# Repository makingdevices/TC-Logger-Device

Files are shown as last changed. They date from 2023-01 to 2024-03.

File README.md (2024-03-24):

<!-- Improved compatibility of back to top link: See: https://github.com/othneildrew/Best-README-Template/pull/73 -->

<!--
*** Thanks for checking out the Best-README-Template. If you have a suggestion
*** that would make this better, please fork the repo and create a pull request
*** or simply open an issue with the tag "enhancement".
*** Don't forget to give the project a star!
*** Thanks again! Now go create something AMAZING! :D
-->

<!-- PROJECT SHIELDS -->
<!--
*** I'm using markdown "reference style" links for readability.
*** Reference links are enclosed in brackets [ ] instead of parentheses ( ).
*** See the bottom of this document for the declaration of the reference variables
*** for contributors-url, forks-url, etc. This is an optional, concise syntax you may use.
*** https://www.markdownguide.org/basic-syntax/#reference-style-links
-->
[][ig-url]
[][sponsor-url]
[][stars-url]
[][issues-url]
[][linkedin-url]

<!-- PROJECT LOGO -->
<br />
<div align="center">
  <a href="https://makingdevices.com/links/">
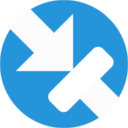
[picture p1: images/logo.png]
    
  </a>

<h3 align="center">Making Devices</h3>

  <p align="center">
    Open Source projects where we struggle with engineering, electronics, coding and who knows what else... In this case, TC Logger Device is a very simple USB thermocouple reader, so hopefully you may find it interesting ;)
  </p>
</div>

<!-- TABLE OF CONTENTS -->
<details>
  <summary>Table of Contents</summary>
  <ol>
    <li>
      <a href="#about-the-project">About The Project</a>
      <ul>
        <li><a href="#built-with">Built With</a></li>
      </ul>
    </li>
    <li>
      <a href="#Build-one">Build one</a>
      <ul>
      </ul>
    </li>
    <li><a href="#usage">Usage</a></li>
    <li><a href="#roadmap">Roadmap</a></li>
    <li><a href="#license">License</a></li>
    <li><a href="#contact">Contact</a></li>
    <li><a href="#Sponsor">Sponsor</a></li>
  </ol>
</details>

<!-- ABOUT THE PROJECT -->
## About The Project

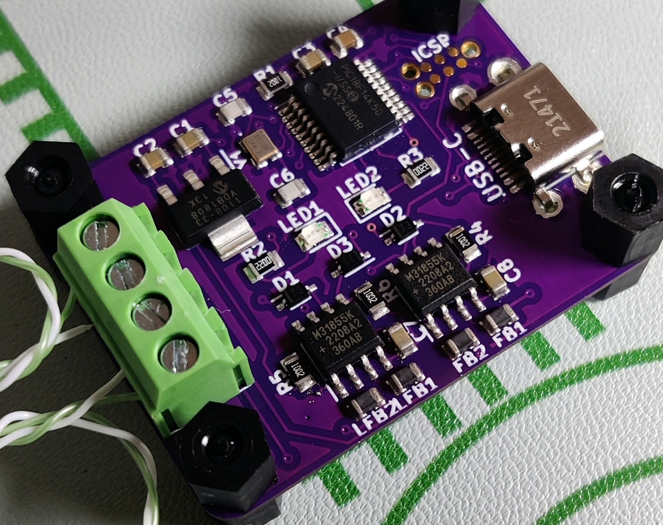
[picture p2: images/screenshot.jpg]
Bytes Counter Shot
[](https://makingdevices.com/TCLogger-Device)

TC Logger Device is a simple thermocouple USB reader: help you to measure any proccess you need using the USB protocol an a simple software developed in Python. The project was chosen to test the USB communication, explore the interface PC-Embedded system. The project is able to use two thermocouple at the same time and share the data to the computer at a speed of 5Hz. (5 samples per second). The main microprocessor is the PIC18F14K50.

<p align="right">(<a href="#readme-top">back to top</a>)</p>

### Built With

[][PIC-url]
[][MPLAB-C-url]
[][kicad-url]
[][sponsor-url]

<p align="right">(<a href="#readme-top">back to top</a>)</p>

<!-- GETTING STARTED -->

## Build one
The project is finished and no further development will be made. The device is safe, stable and It was tested. 

1. Get the gerber files for the latest version: [V1.2b](https://github.com/makingdevices/TC-Logger-Device/blob/main/Gerber/v1.2b/ThermoDeviceLogger-v_1.2b.zip) 
2. Send them to a PCB manufacturer ([Our Sponsor is PCBWAY][sponsor-url])
3. You can read the user manual: [V1.0](https://github.com/makingdevices/TC-Logger-Device/blob/main/Output_PDF/Manual_ThermoLoggerv1_0.pdf) 

<p align="right">(<a href="#readme-top">back to top</a>)</p>

<!-- USAGE EXAMPLES -->
## Usage

Instructions of use:

- The LED will light up if a thermocouple is not detected.
- Use the Python software to communicate with the board.

You can read the user manual: [V1.0](https://github.com/makingdevices/TC-Logger-Device/blob/main/Output_PDF/Manual_ThermoLoggerv1_0.pdf) 

<p align="right">(<a href="#readme-top">back to top</a>)</p>

<!-- ROADMAP -->
## Roadmap

- [x] Finish the firmware for the PIC18F14K50
- [x] Validate firmware
- [x] Finish PC software
    - [x] Implement SCPI commands 
    - [x] Add data records 
    - [X] Improve thermocouple graphs
    - [x] Add Device Info page

See the [open issues](https://github.com/makingdevices/Thermo-device-logger/issues) for a full list of proposed features (and known issues).

State: Project <b>FINISHED</b> - 26/09/2023

Priority: <b>High</b>

<!-- SCPI -->
## SCPI Commands

- :MEAS  
  - :TC1
    - :INT?
    - :EXT?
    - :LED?
  - :TC2 
    - :INT?
    - :EXT?
    - :LED?
- :SET  
  - :TC1
    - :LED [AUTO|0|1] 
  - :TC2
    - :LED [AUTO|0|1] 
- :MODE   
  - :LED
    - :TC1?
    - :TC2?
- :CONF  
    - :APP?
    - :HW?
- *IDN?  
- :hello? 

<p align="right">(<a href="#readme-top">back to top</a>)</p>

<!-- LICENSE -->
## License

Distributed under three licenses:
- [Hardware](/License/HW_cern_ohl_s_v2.pdf)
- [Software](/License/SW_GPLv3.0.txt)
- [Documentation](/License/Documentation_CC-BY-SA-4.0.txt)

OSHW LICENSE: [ES000034](https://certification.oshwa.org/es000034.html)

[GPL v3 License][license-url] 
<p align="right">(<a href="#readme-top">back to top</a>)</p>

<!-- CONTACT -->
## Contact

Making Devices - [@MakingDevices](https://www.instagram.com/makingdevices/)

Project Link: [https://github.com/makingdevices/TC-Logger-Device/](https://github.com/makingdevices/TC-Logger-Device/)

Other Links: [LinkTree](https://makingdevices.com/links/)

<p align="right">(<a href="#readme-top">back to top</a>)</p>

<!-- Sponsor -->
## Sponsor

[PCBWAY](https://www.pcbway.com/?from=makingdevices) is the most professional PCB manufacturer for prototyping and low-volume production to work with in the world. With more than a decade in the field, They are committed to meeting the needs of their customers from different industries in terms of quality, delivery, cost-effectiveness and any other demanding requests. As Sponsor of Making Devices, they will be in charge of all the PCBs for MDV, allowing both of us to grow together in a long term partnership. We hope you take them into account for your both personal and professional prototypes or products.

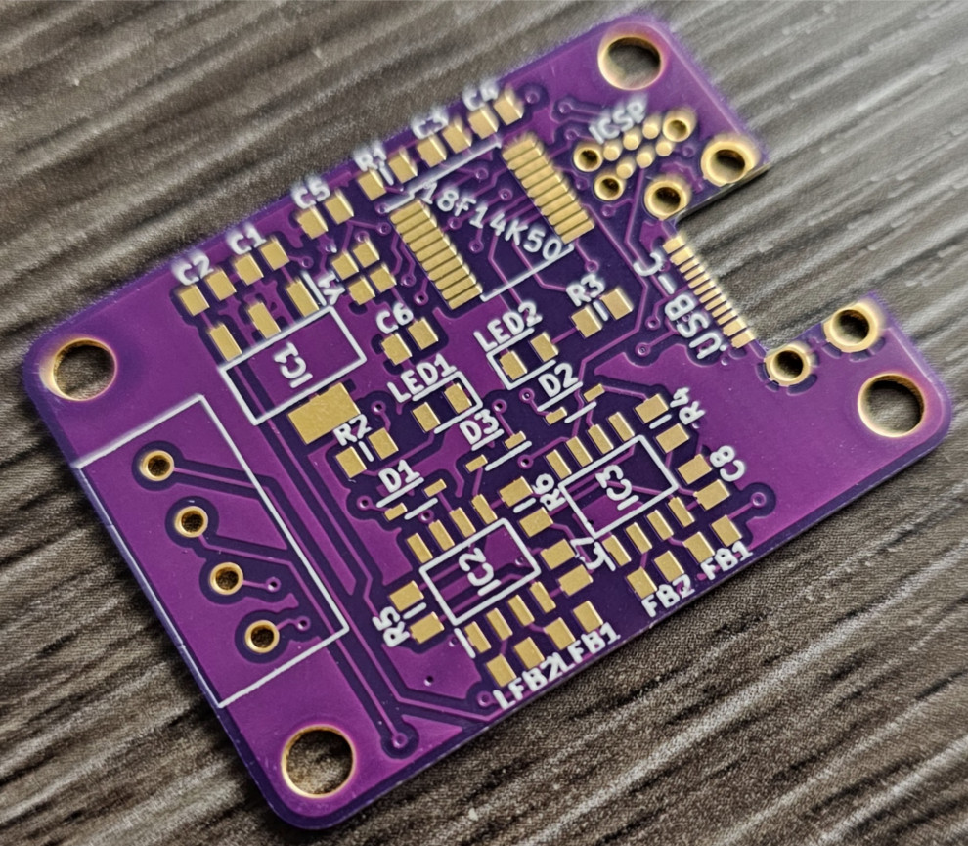
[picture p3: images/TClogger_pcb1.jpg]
[][sponsor-url]
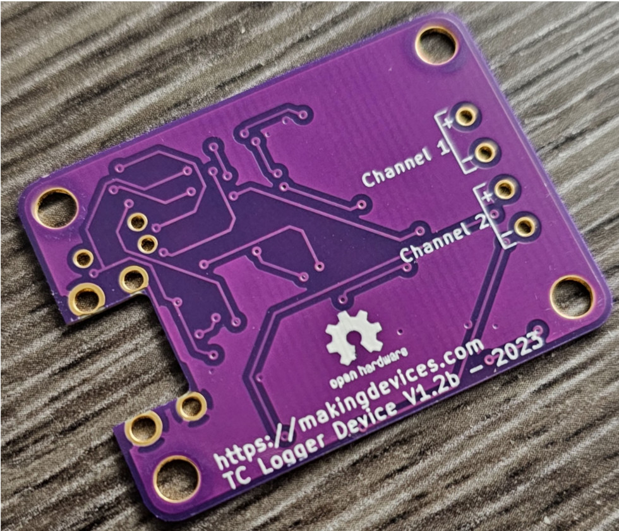
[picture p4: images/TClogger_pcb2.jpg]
[][sponsor-url]

Should you want to colaborate with MakingDevices, you can buy a [TC Logger Device fully assembled and ready to use](https://www.pcbway.com/project/gifts_detail/TC_Logger_Device_5464ceb2.html)

<p align="right">(<a href="#readme-top">back to top</a>)</p>

<!-- MARKDOWN LINKS & IMAGES -->
<!-- https://www.markdownguide.org/basic-syntax/#reference-style-links -->
[contributors-shield]: https://img.shields.io/github/contributors/makingdevices/Thermo-device-logger.svg?style=for-the-badge
[contributors-url]: https://github.com/makingdevices/Thermo-device-logger/graphs/contributors
[forks-shield]: https://img.shields.io/github/forks/makingdevices/Thermo-device-logger.svg?style=for-the-badge
[forks-url]: https://github.com/makingdevices/Thermo-device-logger/network/members
[stars-shield]: https://img.shields.io/github/stars/makingdevices/Thermo-device-logger.svg?style=for-the-badge
[stars-url]: https://github.com/makingdevices/Thermo-device-logger/stargazers
[issues-shield]: https://img.shields.io/github/issues/makingdevices/Thermo-device-logger.svg?style=for-the-badge
[issues-url]: https://github.com/makingdevices/Thermo-device-logger/issues
[license-shield]: /images/license.png
[license-url]: https://github.com/makingdevices/Thermo-device-logger/tree/main/License
[linkedin-shield]: https://img.shields.io/badge/-LinkedIn-black.svg?style=for-the-badge&logo=linkedin&colorB=555
[linkedin-url]: https://www.linkedin.com/company/making-devices/
[sponsor-shield]: https://img.shields.io/badge/SPONSOR-PCBWAY-black.svg?style=for-the-badge&colorB=1200
[sponsor-url]: https://www.pcbway.com/?from=makingdevices
[sponsor-screenshot]: /images/PCB_sponsor.png
[sponsor-pcb-1]: /images/TClogger_pcb1.jpg
[sponsor-pcb-2]: /images/TClogger_pcb2.jpg
[product-screenshot]: images/screenshot.jpg
[PIC]: https://img.shields.io/badge/PIC18LF14K50-000000?style=for-the-badge
[PIC-url]: http://ww1.microchip.com/downloads/en/devicedoc/40001350f.pdf
[kicad-shield]: https://img.shields.io/badge/kicad-0b03fc?style=for-the-badge&logo=kicad&logoColor=white
[kicad-url]: https://www.kicad.org/
[YT-screenshot]: images/YT_assembly.PNG
[sponsor-icon]:  https://img.shields.io/badge/-PCBWAY-black.svg?style=for-the-badge&colorB=1200
[ig-shield]: https://img.shields.io/badge/instagram-a83297?style=for-the-badge&logo=instagram&logoColor=white
[ig-url]: https://www.instagram.com/makingdevices/
[MPLAB-C]: https://img.shields.io/badge/MPLAB%20C18-DD0031?style=for-the-badge&logo=C&logoColor=white
[MPLAB-C-url]: https://www.microchip.com/en-us/development-tool/SW006011
[Svelte.dev]: https://img.shields.io/badge/Svelte-4A4A55?style=for-the-badge&logo=svelte&logoColor=FF3E00
[Svelte-url]: https://svelte.dev/
[Laravel.com]: https://img.shields.io/badge/Laravel-FF2D20?style=for-the-badge&logo=laravel&logoColor=white
[Laravel-url]: https://laravel.com
[Bootstrap.com]: https://img.shields.io/badge/Bootstrap-563D7C?style=for-the-badge&logo=bootstrap&logoColor=white
[Bootstrap-url]: https://getbootstrap.com
[JQuery.com]: https://img.shields.io/badge/jQuery-0769AD?style=for-the-badge&logo=jquery&logoColor=white
[JQuery-url]: https://jquery.com

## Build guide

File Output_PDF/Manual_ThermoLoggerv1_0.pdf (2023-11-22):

The same manual applies for Linux, Windows and Mac users. Depending of your setup, you will need to run the python code directly, or you can use the lazy compiled version for windows. Once opened the program, you will see the following screen:

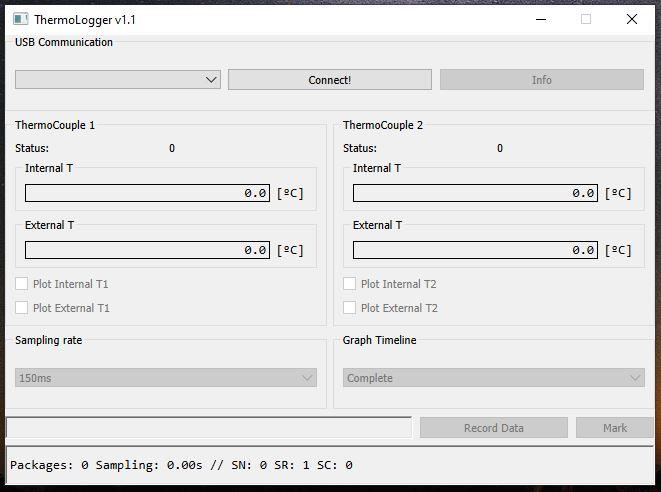
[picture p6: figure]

Figure 1: ThermoLogger v1.1 software main windows.

In the upper part of the windows, you will see a blank combobox under “USB Communication”. Now you can connect the board to the USB of your computer. No extra drivers are needed. Then the COMPORT will should appear as shown in next picture:

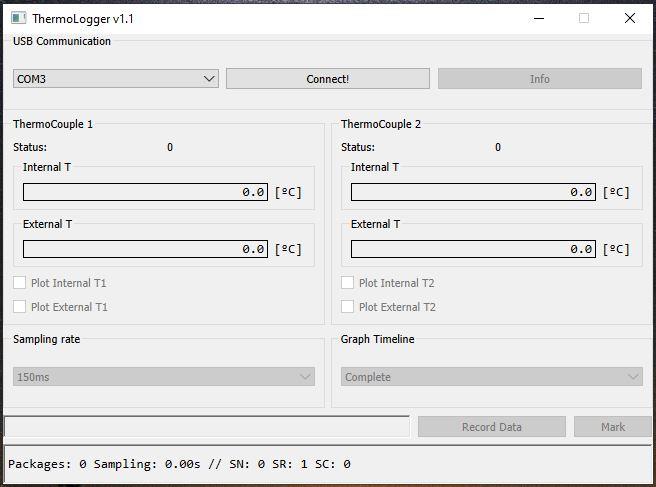
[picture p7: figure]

Figure 2: A board is detected at COM3.

Once you clicked “Connect!”, all the options will enable for you to use:

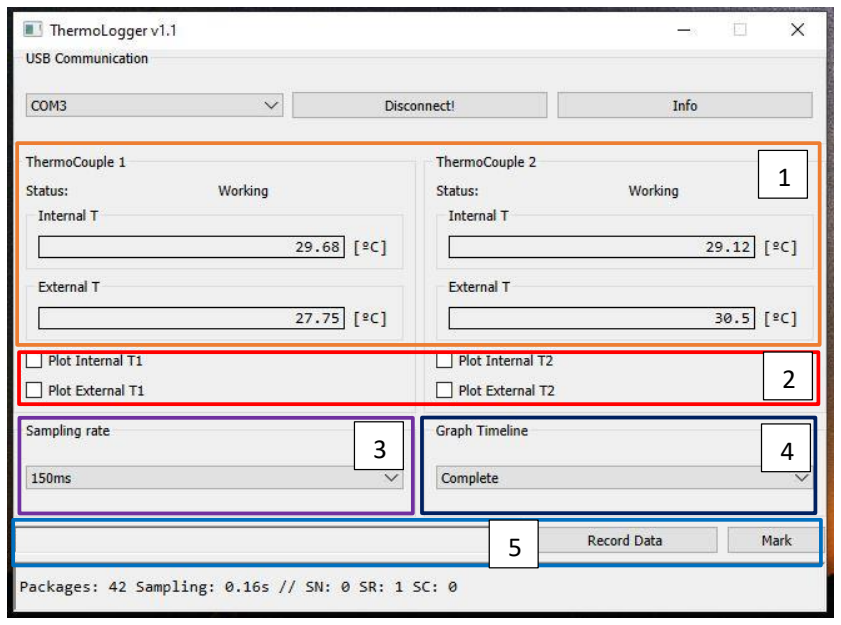
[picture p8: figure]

Figure 3: Sections of the software.

1. The values from the thermocouple and the status of each one. It can detect any short between wires, to ground, or if the thermocouple is disconnected. The “internal T” is the temperature of the ADC over the board, so it is not relevant for measurements.
2. You can tick or untick those boxes to add the curve to the graph:

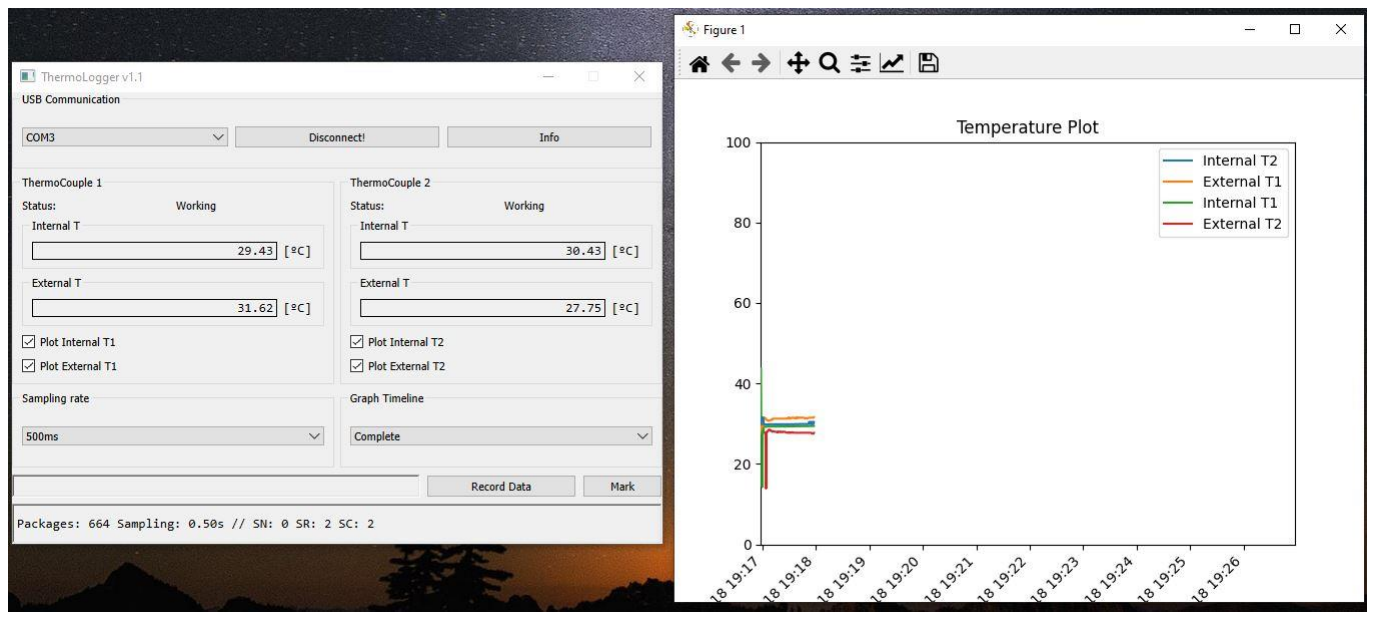
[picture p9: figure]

Figure 4: The graph window will pop-up as soon as any box is ticked

You can change the plot in real time. In addition, you can modify the view, Y and X axis, colors and curves colors in the graph windows. Furthermore, you can export the graph as picture or vector using the options of the same windows.

3. You can select the sampling rate, but it has a trick: Only 150ms or 250ms are functional. Any value above this values will sample every 250ms and make an average data until the sampling rate required is achieved, acting as a Low Pass Filter.

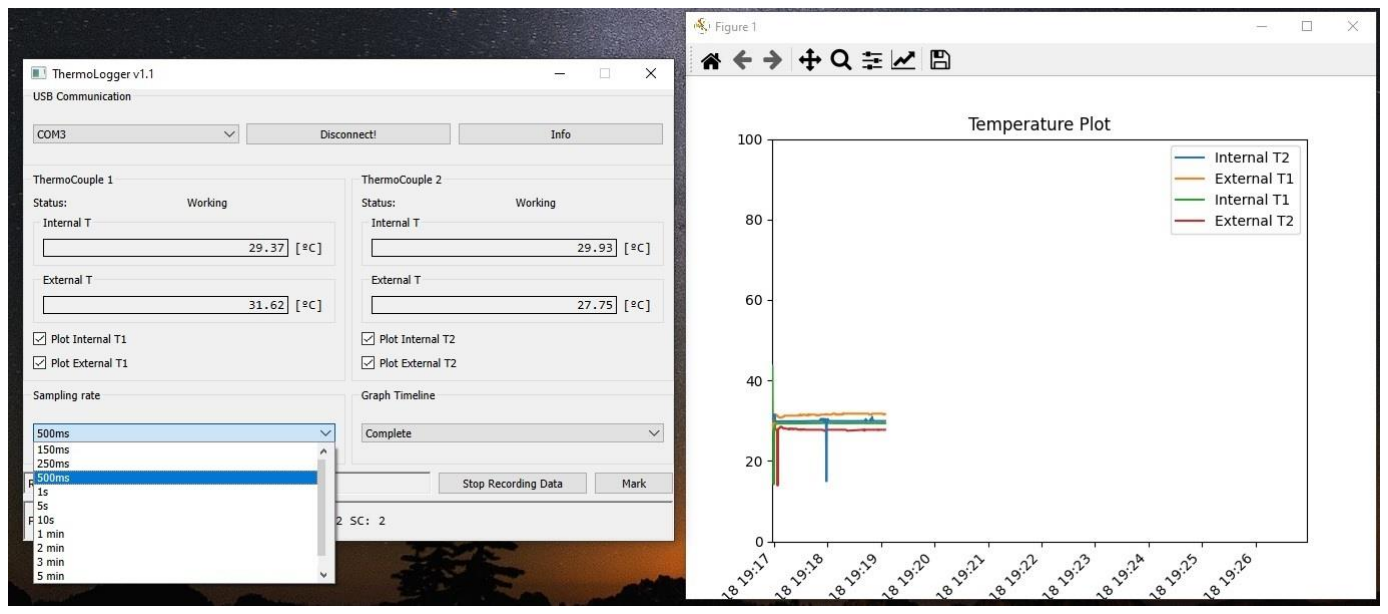
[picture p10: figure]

Figure 5: Sampling rate selection.

4. Graph timeline: This will help you change the X-axis of the graph manually. You can select from different timelines, but we recommend to leave it as “Complete”, so the X-axis will include all the temperature curves.

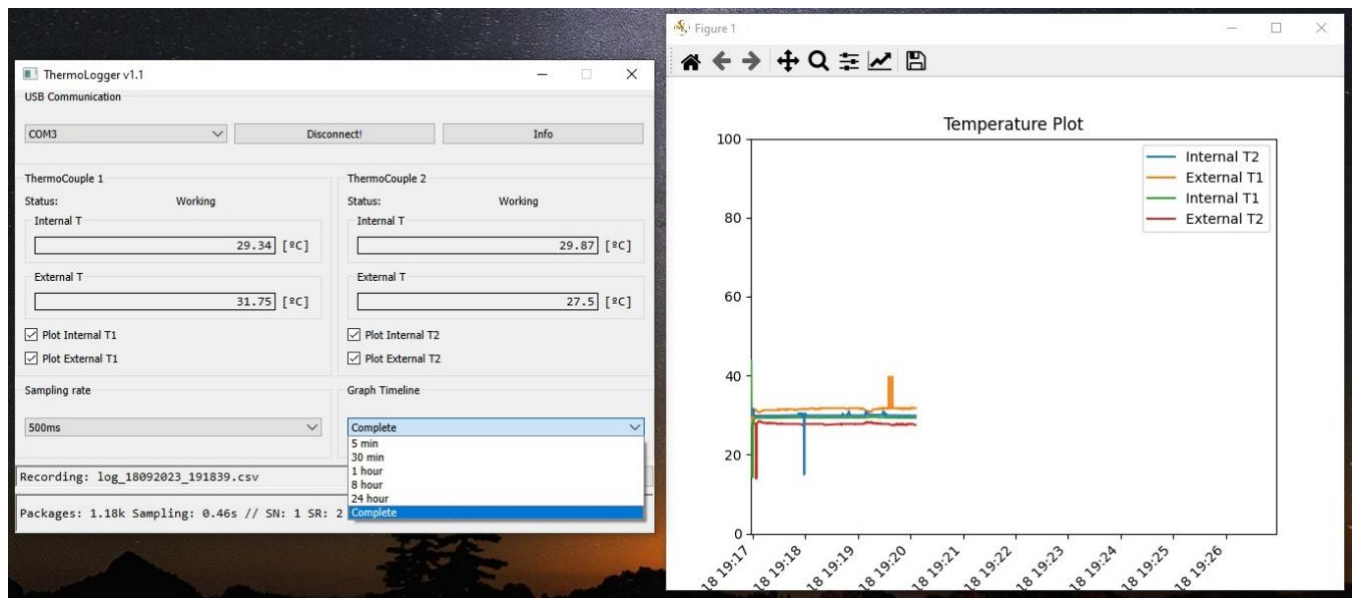
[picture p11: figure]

Figure 6: Graph timeline menu selection.

5. In the fifth selection we have the recording data section. By clicking “record data” we start to record all the data in a .csv file inside “Data” folder:

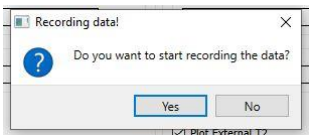
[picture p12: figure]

Figure 6: The user is asked to start recording the data.

As soon as we click Yes in the pop-up, a .csv file with the date will be created. The “Mark” button will create a Mark in the file, so you can keep track of the time you change anything during the test. (Example: You can mark whenever you change the temperature of the oven you are measuring, so later on when reviewing the .csv file, you will see the mark). You can make as many mark as you want.

Finally, the bottom bar is for debugging, as it includes the following data:

Number of packages: The number of packages received from the board.
Sampling: The time (in seconds) of the last data printed in graph and screen. Should coincide with the Sampling Rate selected on the GUI.
SN: Sample Number inside the average loop
SR: Number of samples we are averaging for every printed sampled.
SC: Sampling Choice (Position of the comboBox).

To end, if you click on the “Info” button, you will extract the info of the FW and HW board you have:

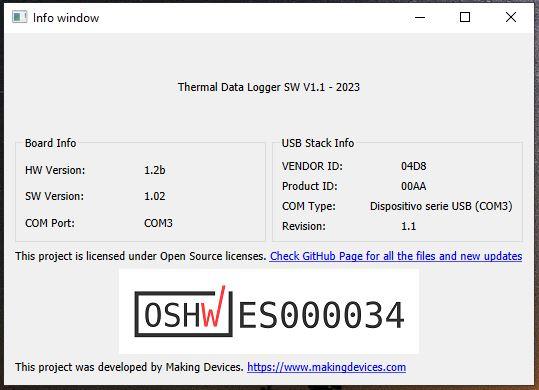
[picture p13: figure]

Figure 7: Info window.

For any requested feature or problem with the software or the board, please contact using the form of https://www.makingdevices.com

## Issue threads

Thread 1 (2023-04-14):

[Requisite][1.2b] SCPI Commands

makingdevices, 2023-04-14:
The device should communicate with the PC using SCPI commands. In addition, except from the "*IDN?" command, the rest should be mixed as the SCPI standard allows.

**Design Process:**

- [x] **MEAS** -> Retrieve the asked measurement.
- [x] **SET** -> Set a LED to a specific state between OFF, ON and AUTOMATIC.
- [x] **MODE** -> Retrieve the LED state.
- [x] **CONF** -> Gives back the version of the HW and FW.
- [x] ***IDN?** -> Gives back information about the device.
- [x] **:hello?** -> Answer back saying hello.

**Validation Process:**
- [x] Write script to test the SCPI Commands
- [x] Test with different computers
- [x] Finish validation

makingdevices, 2023-08-01:
Hardware fully validated

Closed 2023-08-01.

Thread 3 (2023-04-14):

[Requisite] [1.2b] USB Communication

makingdevices, 2023-04-14:
The board should communicate with the computer with the embedded USB Type C connector. No need for extra drivers or boards. The board will be powered from the USB.

**Design Process:**

- [x] USB STACK in Microchip

**Validation Process:**

- [x] USB is detected in different computers.
- [x] No drivers needed

makingdevices, 2023-08-01:
Tested in different computers

Closed 2023-08-01.

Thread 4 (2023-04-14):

[Requisite] [1.2b] LED indicators

makingdevices, 2023-04-14:
The board should have two LED Indicators. These are intented to show the user if there is any problem with the thermocouple.

**Design Process:**

- [ ] The PCB has two led indicators
- [ ] The LED is ON when the attached thermocouple has any problem

**Validation Process**

- [ ]  The LED work as intended

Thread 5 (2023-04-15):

[Requisite][1.2b] Thermocouple Reading

makingdevices, 2023-04-15:
The logger device needs to work with Thermocouples type K. In addition, the speed will be for at least 2Hz or 2 reading every second. The precision will be +-0.1C

Process Design:
- [x] Find IC chip for thermocouple readings
- [x] Implement the communication between main IC and ADC

Validation Design:

- [x] The data is reliable and fast enough

Closed 2023-04-20.

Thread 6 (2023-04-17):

[PC Software] [1.0] Features for the PC software

makingdevices, 2023-04-17:
There will be a PC Software developed in Python to control and measure temperatures with the TC-Logger-Device. The features are:

- [x] Works with SCPI commands.
- [x] Read both channels temperatures from the board.
- [x] Able to plot internal, external or both temperatures.
- [x] Variable sampling rate.
- [x] X-axis should be time-based, not sample-based
- [x] Variable graph X-axis: different timelines
- [x] Able to export all the data into a .csv
- [x] Auto-detect when device plugged.
- [x] Info tab to see the HW and FW version of the board.
- [x] Debugger info bar at the bottom

The release will be the Stable v1 version

makingdevices, 2023-09-13:
Added CSV export feature

makingdevices, 2023-09-13:
Added from 150ms up to 10 min sampling rate. When the sampling rate is higher than 250ms, it applied a low pass filter (average) for the previous points.

makingdevices, 2023-09-16:
Added debug bar! it is close to the end!

makingdevices, 2023-09-16:
X-axis is now time-based, so it should be easy to add different timelines now.

makingdevices, 2023-09-17:
Added different timelines for the graph

makingdevices, 2023-09-17:
Software completed. I will upload some documentation for the use of the software, and a .exe for Windows and the project will be completed

Closed 2023-09-17.

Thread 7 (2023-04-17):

Write some examples of code

makingdevices, 2023-04-17:
There will be some code examples (In python) so anyone can develop its own version of the software.

- [x] How to read internal temperature for a channel
- [x] How to read external temperature for a channel
- [x] How to read the version of the software and board
- [x] How to read the info about the board
- [x] How to set a LED ON or OFF
- [x] Auto-test script.

makingdevices, 2023-08-01:
Everything is on the repository ./Python-Examples

Closed 2023-08-01.

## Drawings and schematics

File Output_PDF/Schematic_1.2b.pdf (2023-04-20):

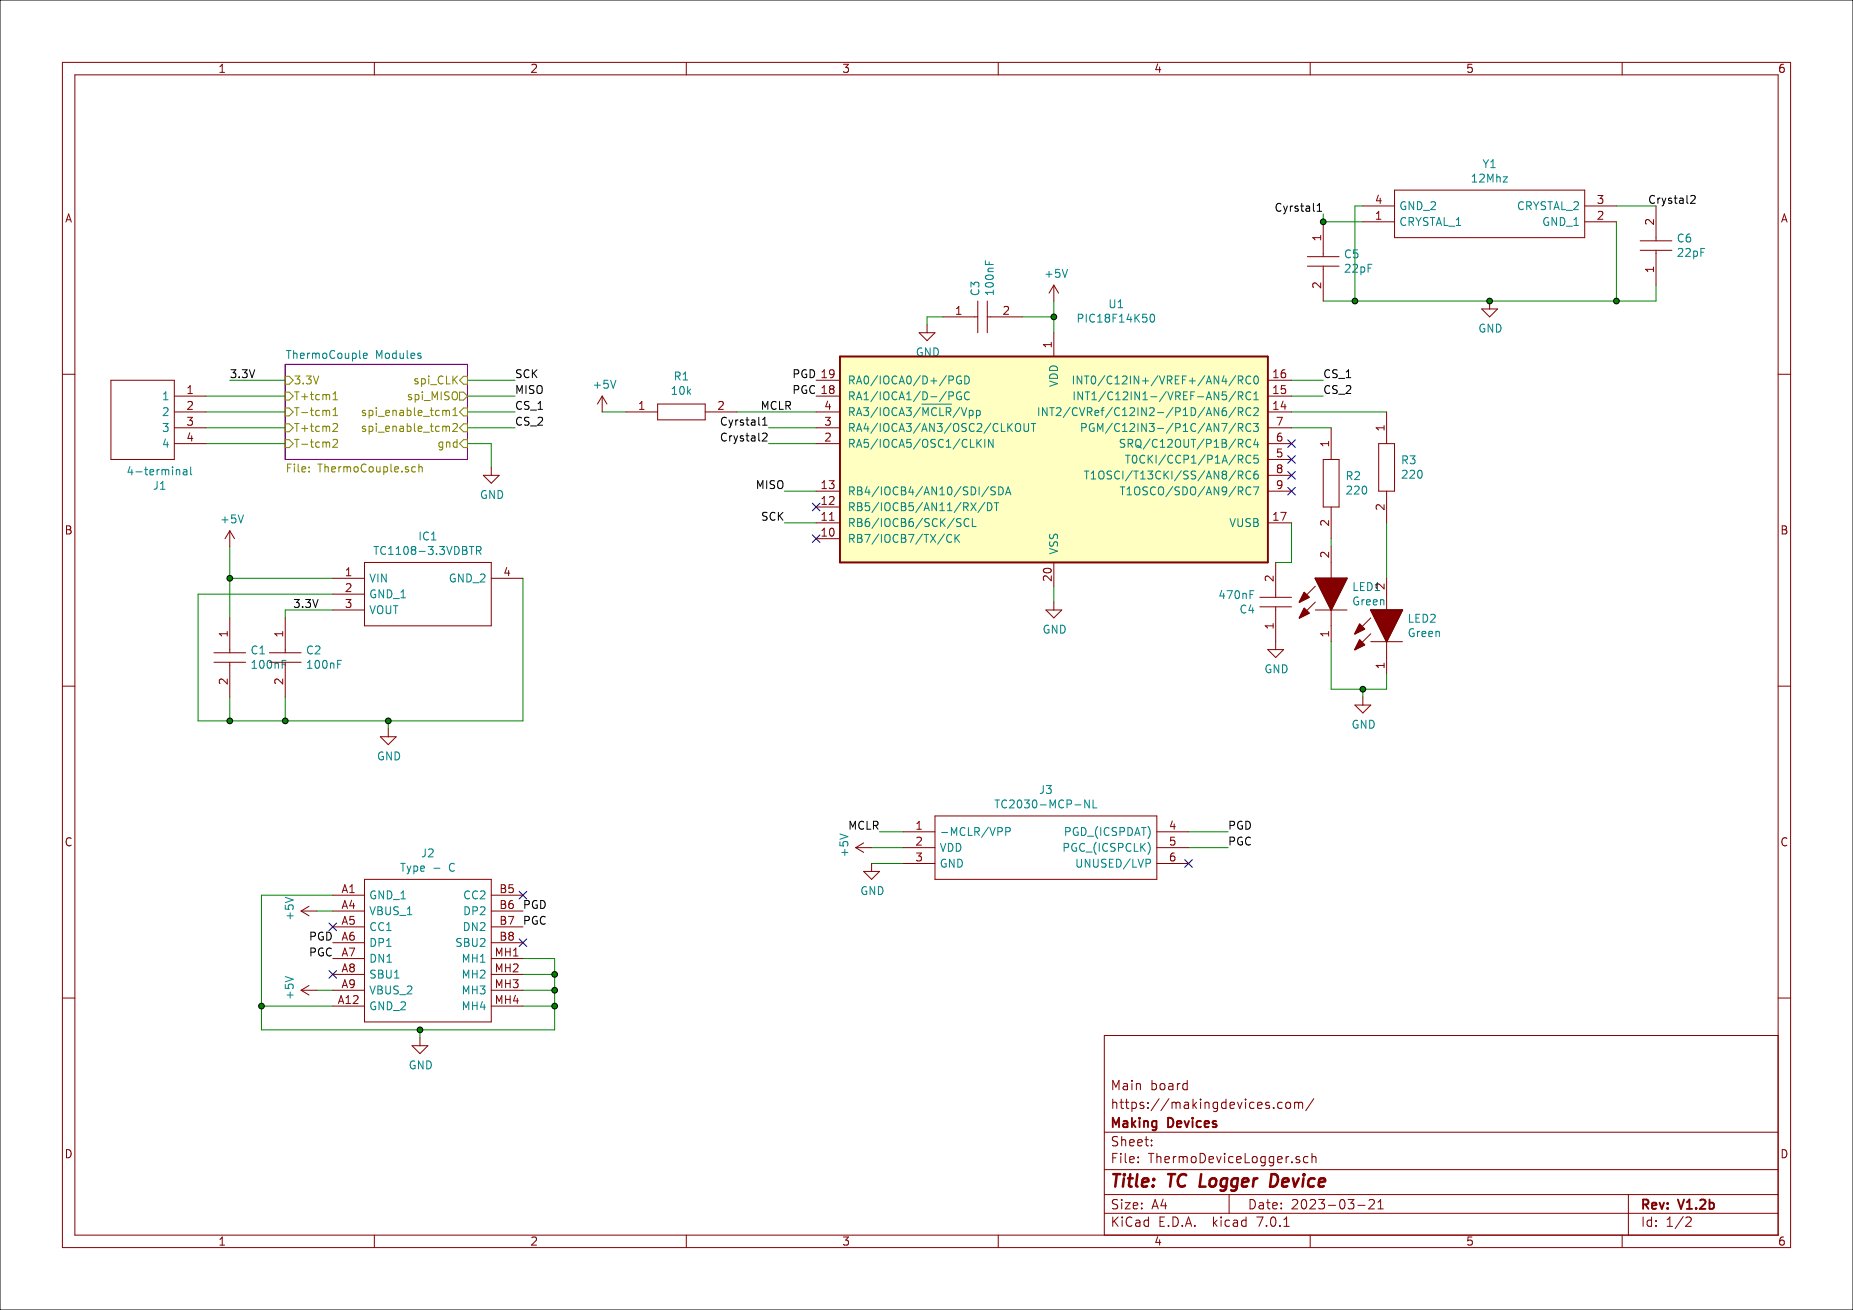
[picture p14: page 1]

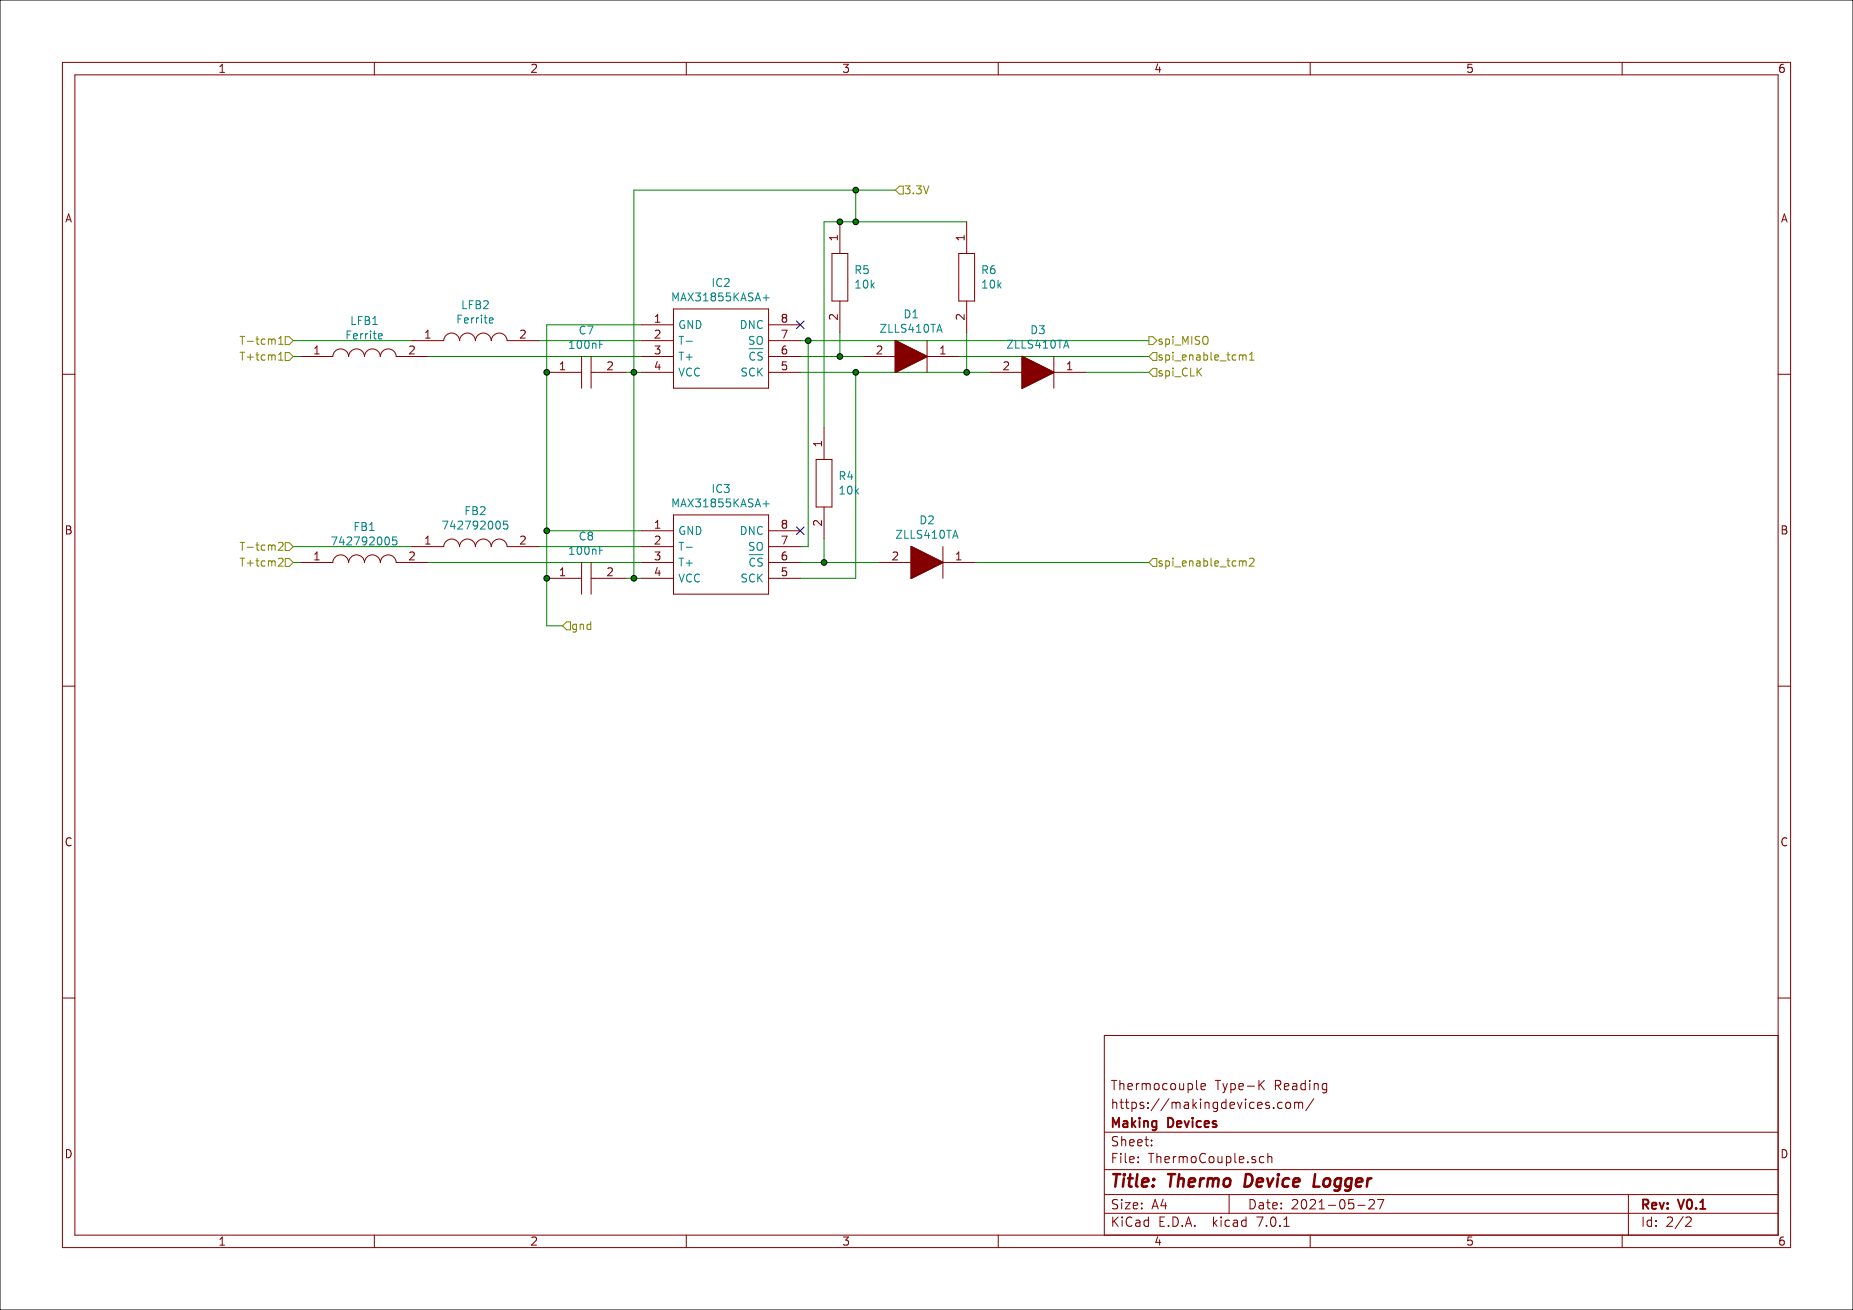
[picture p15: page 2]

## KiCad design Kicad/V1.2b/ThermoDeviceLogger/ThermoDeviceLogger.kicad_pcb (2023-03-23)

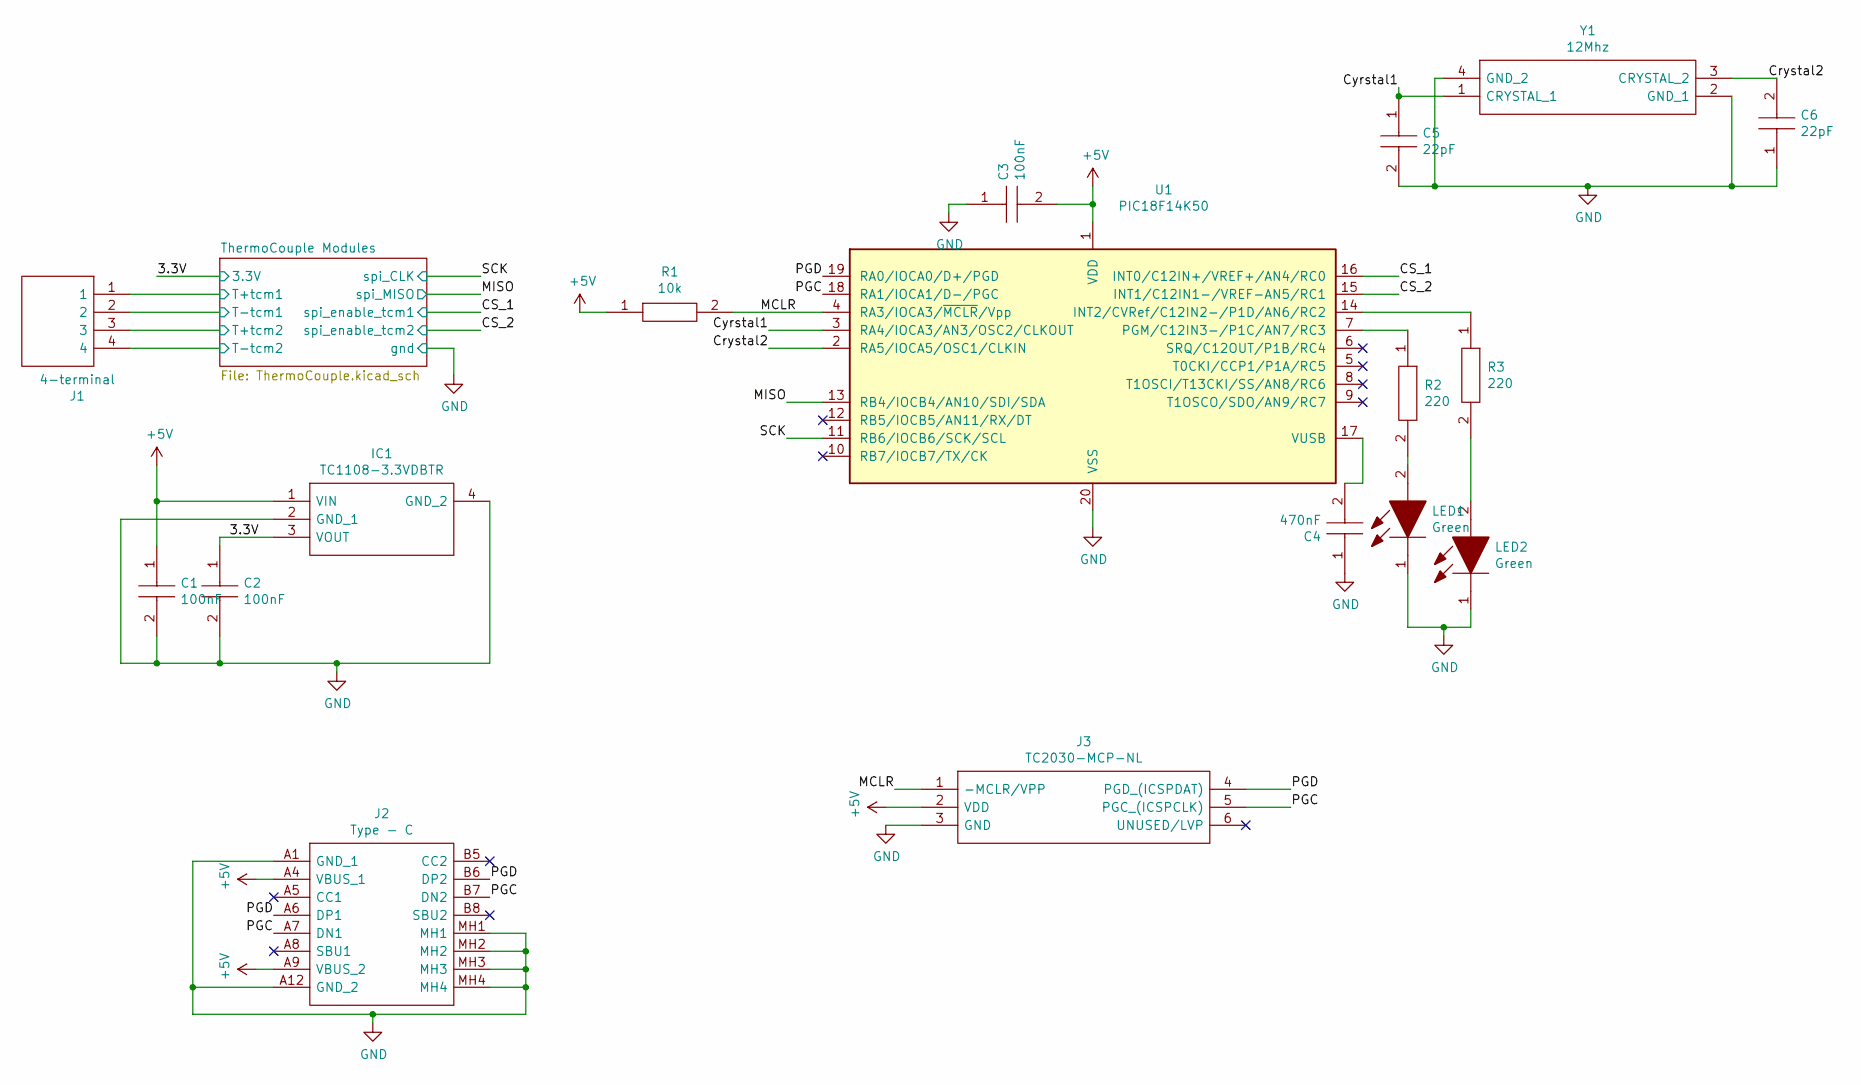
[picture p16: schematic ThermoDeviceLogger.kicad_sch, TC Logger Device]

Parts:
C1, C2, C3: 100nF; CAPC2012X140N; Manufacturer_Part_Number C0805C475M8RACTU
C4: 470nF; CAPC2012X140N; Manufacturer_Part_Number C0805C475M8RACTU
C5, C6: 22pF; CAPC2012X140N; Manufacturer_Part_Number C0805C475M8RACTU
IC1: TC1108-3.3VDBTR; SOT230P700X180-4N; Manufacturer_Part_Number TC1108-3.3VDBTR
J1: 4-terminal; 1751264; Manufacturer_Part_Number 1751264
J2: Type - C; 2169900003; Mouser Part Number 538-216990-0003
J3: TC2030-MCP-NL; Manufacturer_Part_Number TC2030-MCP-NL
LED1, LED2: Green; LEDC2012X90N; Manufacturer_Part_Number SML-H12V8TT86
R1: 10k; RESC2012X75N; Manufacturer_Part_Number ERJP6WF1303V
R2, R3: 220; RESC2012X75N; Manufacturer_Part_Number ERJP6WF1303V
U1: PIC18F14K50; SSOP-20_5.3x7.2mm_P0.65mm
Y1: 12Mhz; CX2520DB12000D0GPSC1; Manufacturer_Part_Number CX2520DB12000D0GPSC1

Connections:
+5V: C1.1, C3.2, IC1.1 (VIN), J2.A4 (VBUS_1), J2.A9 (VBUS_2), J3.2 (VDD), R1.1, U1.1 (VDD); also elsewhere on the board
/3.3V: C2.1, IC1.3 (VOUT); also elsewhere on the board
/CS_1: U1.16 (INT0/C12IN+/VREF+/AN4/RC0); also elsewhere on the board
/CS_2: U1.15 (INT1/C12IN1-/VREF-AN5/RC1); also elsewhere on the board
/Crystal2: C6.2, U1.2 (RA5/IOCA5/OSC1/CLKIN), Y1.3 (CRYSTAL_2)
/Cyrstal1: C5.1, U1.3 (RA4/IOCA3/AN3/OSC2/CLKOUT), Y1.1 (CRYSTAL_1)
/MCLR: J3.1 (-MCLR/VPP), R1.2, U1.4 (RA3/IOCA3/~MCLR/Vpp); also elsewhere on the board
/MISO: U1.13 (RB4/IOCB4/AN10/SDI/SDA); also elsewhere on the board
/PGC: J2.A7 (DN1), J2.B7 (DN2), J3.5 (PGC_(ICSPCLK)), U1.18 (RA1/IOCA1/D-/PGC); also elsewhere on the board
/PGD: J2.A6 (DP1), J2.B6 (DP2), J3.4 (PGD_(ICSPDAT)), U1.19 (RA0/IOCA0/D+/PGD); also elsewhere on the board
/SCK: U1.11 (RB6/IOCB6/SCK/SCL); also elsewhere on the board
/ThermoCouple Modules/T+tcm1: J1.1; also elsewhere on the board
/ThermoCouple Modules/T+tcm2: J1.3; also elsewhere on the board
/ThermoCouple Modules/T-tcm1: J1.2; also elsewhere on the board
/ThermoCouple Modules/T-tcm2: J1.4; also elsewhere on the board
GND: C1.2, C2.2, C3.1, C4.1, C5.2, C6.1, IC1.2 (GND_1), IC1.4 (GND_2), J2.A1 (GND_1), J2.A12 (GND_2), J2.MH1, J2.MH2, J2.MH3, J2.MH4, J3.3 (GND), LED1.1, LED2.1, U1.20 (VSS), Y1.2 (GND_1), Y1.4 (GND_2); also elsewhere on the board
unnamed: C4.2, U1.17 (VUSB)
unnamed: LED1.2, R2.2
unnamed: LED2.2, R3.2
unnamed: R2.1, U1.7 (PGM/C12IN3-/P1C/AN7/RC3)
unnamed: R3.1, U1.14 (INT2/CVRef/C12IN2-/P1D/AN6/RC2)

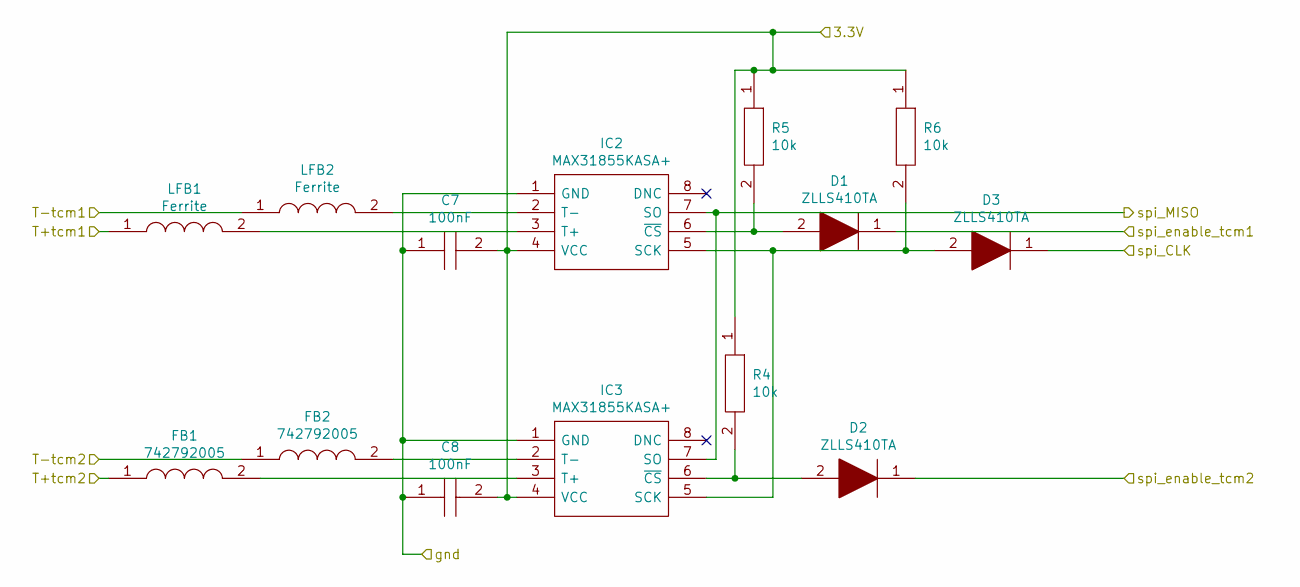
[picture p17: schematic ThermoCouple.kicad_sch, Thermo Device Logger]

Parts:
C7, C8: 100nF; CAPC2012X140N; Manufacturer_Part_Number C0805C475M8RACTU
D1, D2, D3: ZLLS410TA; SOD2513X120N; Manufacturer_Part_Number ZLLS410TA
FB1, FB2: 742792005; CAPC2012X90N; Manufacturer_Part_Number 742792005
IC2, IC3: MAX31855KASA+; SOIC127P600X175-8N; Manufacturer_Part_Number MAX31855KASA+
LFB1, LFB2: Ferrite; CAPC2012X90N; Manufacturer_Part_Number 742792005
R4, R5, R6: 10k; RESC2012X75N; Manufacturer_Part_Number ERJP6WF1303V

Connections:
/3.3V: C7.2, C8.2, IC2.4 (VCC), IC3.4 (VCC), R4.1, R5.1, R6.1; also elsewhere on the board
/CS_1: D1.1; also elsewhere on the board
/CS_2: D2.1; also elsewhere on the board
/MISO: IC2.7 (SO), IC3.7 (SO); also elsewhere on the board
/SCK: D3.1; also elsewhere on the board
/ThermoCouple Modules/T+tcm1: LFB1.1; also elsewhere on the board
/ThermoCouple Modules/T+tcm2: FB1.1; also elsewhere on the board
/ThermoCouple Modules/T-tcm1: LFB2.1; also elsewhere on the board
/ThermoCouple Modules/T-tcm2: FB2.1; also elsewhere on the board
GND: C7.1, C8.1, IC2.1 (GND), IC3.1 (GND); also elsewhere on the board
unnamed: D1.2, IC2.6 (~CS), R5.2
unnamed: D2.2, IC3.6 (~CS), R4.2
unnamed: D3.2, IC2.5 (SCK), IC3.5 (SCK), R6.2
unnamed: FB1.2, IC3.3 (T+)
unnamed: FB2.2, IC3.2 (T-)
unnamed: IC2.2 (T-), LFB2.2
unnamed: IC2.3 (T+), LFB1.2

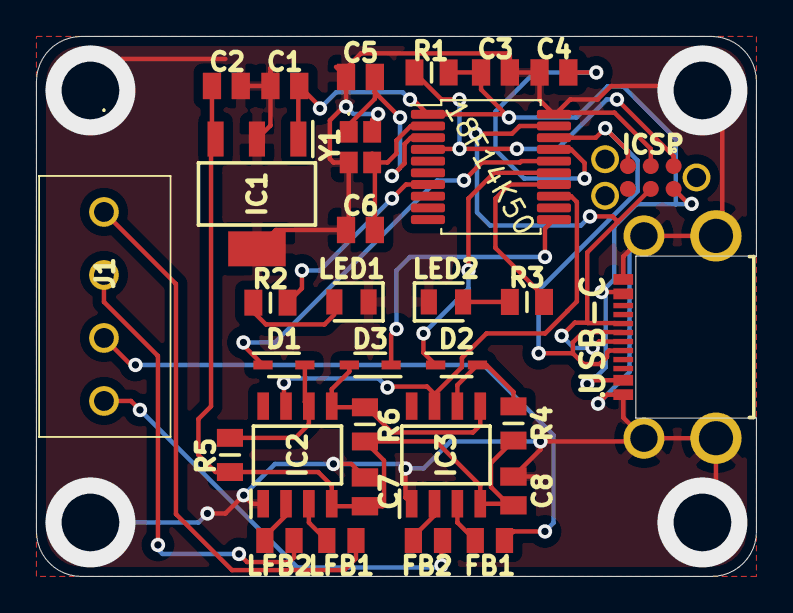
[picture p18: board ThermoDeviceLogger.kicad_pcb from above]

Board: 2 copper layers, 40.0 x 30.0 mm, 31 parts (0 on the bottom side), 28 nets.

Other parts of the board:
ICSP: TC2030-MCP-NL
USB-C: Type - C; 2169900003

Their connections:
+5V: ICSP.2, USB-C.A4, USB-C.A9; also elsewhere on the board
/MCLR: ICSP.1; also elsewhere on the board
/PGC: ICSP.5, USB-C.A7, USB-C.B7; also elsewhere on the board
/PGD: ICSP.4, USB-C.A6, USB-C.B6; also elsewhere on the board
GND: ICSP.3, USB-C.A1, USB-C.A12, USB-C.MH1, USB-C.MH2, USB-C.MH3, USB-C.MH4; also elsewhere on the board

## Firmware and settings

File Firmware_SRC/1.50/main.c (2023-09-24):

/********************************************************************

Making Devices - 2023 CDC FOR PIC18F14K50
https://makingdevices.com/links/

*********************************************************************/

/********************************************************************
 FileName:      main.c
 Dependencies:  See INCLUDES section
 Processor:     PIC18F14K50 USB Microcontroller
 Hardware:      This demo is natively intended to be used on Microchip USB demo
                boards supported by the MCHPFSUSB stack.  See release notes for
                support matrix.  This demo can be modified for use on other 
                hardware platforms.
 Complier:      Microchip C18 (for PIC18)
 Company:       Microchip Technology, Inc.

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
/** INCLUDES *******************************************************/
#include "./USB/usb.h"
#include "./USB/usb_function_cdc.h"
#include "spi.h"

#include "HardwareProfile.h"

/** CONFIGURATION **************************************************/

#if defined(LOW_PIN_COUNT_USB_DEVELOPMENT_KIT)
        #pragma config CPUDIV = NOCLKDIV
        #pragma config USBDIV = OFF
        #pragma config FOSC   = HS
        #pragma config PLLEN  = ON
        #pragma config FCMEN  = OFF
        #pragma config IESO   = OFF
        #pragma config PWRTEN = OFF
        #pragma config BOREN  = ON
        #pragma config BORV   = 30
        #pragma config WDTEN  = OFF
        #pragma config WDTPS  = 32768
        #pragma config MCLRE  = OFF
        #pragma config HFOFST = OFF
        #pragma config STVREN = ON
        #pragma config LVP    = OFF
        #pragma config XINST  = OFF
        #pragma config BBSIZ  = OFF
        #pragma config CP0    = OFF
        #pragma config CP1    = OFF
        #pragma config CPB    = OFF
        #pragma config WRT0   = OFF
        #pragma config WRT1   = OFF
        #pragma config WRTB   = OFF
        #pragma config WRTC   = OFF
        #pragma config EBTR0  = OFF
        #pragma config EBTR1  = OFF
        #pragma config EBTRB  = OFF       
    #else
        #error No hardware board defined, see "HardwareProfile.h" and __FILE__
    #endif

/** I N C L U D E S **********************************************************/

#include "GenericTypeDefs.h"
#include "Compiler.h"
#include "usb_config.h"
#include "USB/usb_device.h"
#include "USB/usb.h"

/** V A R I A B L E S *******************************************************/
#if defined(__18CXX)
    #pragma udata				
#endif

char USB_In_Buffer[34];         //USB IN BUFFER
char USB_In_Buffer_2[8];         //USB IN BUFFER TWO
char index_data = 0; //Number of data to send
char USB_IDN_Buffer[55] = {'C','D','C',' ','T','C',' ','L','O','G','G','E','R',' ','D','E','V','I','C','E',' ','B','Y',' ','M','A','K','I','N','G',' ','D','E','V','I','C','E','S',' ','H','W',':','1','.','2','b',' ','F','W',':','1','.','5','0','\n'};
char USB_Out_Buffer[64];		//USB OUT BUFFER
unsigned char SPI_response[8];  
unsigned char SPI_lastmessage[8];
char spi_state = 0;
char length;
char LED[2] = {0,0};
int convtemperature = 0;
int convtemperature_decimal = 0;
unsigned int rem;
char com_var = 0;
char index = 0;
char index_two = 0;
unsigned char meas_1 = 0;
unsigned char meas_2 = 0;
unsigned char meas_3 = 0;
int i;
char loop = 0;
char length_first = 0;
char length_second = 0;
char offset,module;

/** P R I V A T E  P R O T O T Y P E S ***************************************/

static void InitializeSystem(void);
void ProcessIO(void);
void USBDeviceTasks(void);
void YourHighPriorityISRCode();
void YourLowPriorityISRCode();
void USBCBSendResume(void);
void UserInit(void);
void Interrupts_enable(void);
void bin2temp(unsigned char binary,unsigned char binary2, unsigned char mode);

/** VECTOR REMAPPING ***********************************************/
#if defined(__18CXX)
	//On PIC18 devices, addresses 0x00, 0x08, and 0x18 are used for
	//the reset, high priority interrupt, and low priority interrupt
	//vectors.  However, the Microchip HID bootloader occupies the
	//0x00-0xFFF program memory region.  Therefore, the bootloader code remaps 
	//these vectors to new locations as indicated below.  This remapping is 
	//only necessary if you wish to be able to (optionally) program the hex file 
	//generated from this project with the USB bootloader.  

	#define REMAPPED_RESET_VECTOR_ADDRESS			0x0040
	#define REMAPPED_HIGH_INTERRUPT_VECTOR_ADDRESS	0x0048
	#define REMAPPED_LOW_INTERRUPT_VECTOR_ADDRESS	0x0050
	#define APP_VERSION_ADDRESS                     0x0056 //Fixed location, so the App FW image version can be read by the bootloader.
	#define APP_SIGNATURE_ADDRESS                   0x0046 //Signature location that must be kept at blaknk value (0xFFFF) in this project (has special purpose for bootloader).

    //--------------------------------------------------------------------------
    //Application firmware image version values, as reported to the bootloader
    //firmware.  These are useful so the bootloader can potentially know if the
    //user is trying to program an older firmware image onto a device that
    //has already been programmed with a with a newer firmware image.
    //Format is APP_FIRMWARE_VERSION_MAJOR.APP_FIRMWARE_VERSION_MINOR.
    //The valid minor version is from 00 to 99.  Example:
    //if APP_FIRMWARE_VERSION_MAJOR == 1, APP_FIRMWARE_VERSION_MINOR == 1,
    //then the version is "1.01"

    #define APP_FIRMWARE_VERSION_MAJOR  1   //valid values 0-255
    #define APP_FIRMWARE_VERSION_MINOR  5   //valid values 0-99
	#define APP_HARDWARE_VERSION_MAJOR  0x01   //valid values 0-255
    #define APP_HARDWARE_VERSION_MINOR  0x02   //valid values 0-99
    //--------------------------------------------------------------------------
	
	#pragma romdata AppVersionAndSignatureSection = APP_VERSION_ADDRESS
	ROM unsigned char AppVersion[2] = {APP_FIRMWARE_VERSION_MINOR, APP_FIRMWARE_VERSION_MAJOR};
	#pragma romdata AppSignatureSection = APP_SIGNATURE_ADDRESS
	ROM unsigned short int SignaturePlaceholder = 0xFFFF;
	
	#pragma code HIGH_INTERRUPT_VECTOR = 0x08
	void High_ISR (void)
	{
	     _asm goto REMAPPED_HIGH_INTERRUPT_VECTOR_ADDRESS _endasm
	}
	#pragma code LOW_INTERRUPT_VECTOR = 0x18
	void Low_ISR (void)
	{
	     _asm goto REMAPPED_LOW_INTERRUPT_VECTOR_ADDRESS _endasm
	}
	extern void _startup (void);        // See c018i.c in your C18 compiler dir
	#pragma code REMAPPED_RESET_VECTOR = REMAPPED_RESET_VECTOR_ADDRESS
	void _reset (void)
	{
	    _asm goto _startup _endasm
	}
	#pragma code REMAPPED_HIGH_INTERRUPT_VECTOR = REMAPPED_HIGH_INTERRUPT_VECTOR_ADDRESS
	void Remapped_High_ISR (void)
	{
	     _asm goto YourHighPriorityISRCode _endasm
	}
	#pragma code REMAPPED_LOW_INTERRUPT_VECTOR = REMAPPED_LOW_INTERRUPT_VECTOR_ADDRESS
	void Remapped_Low_ISR (void)
	{
	     _asm goto YourLowPriorityISRCode _endasm
	}
	#pragma code
	
	
	//These are your actual interrupt handling routines.
	#pragma interrupt YourHighPriorityISRCode
	void YourHighPriorityISRCode()
	{
        #if defined(USB_INTERRUPT)
	        USBDeviceTasks();
        #endif
		
		if(INTCONbits.TMR0IF) //Timer0 interrupt
			{
				//We set the timer0 again
				TMR0H = 0x50;
				TMR0L = 0x38;
				INTCONbits.TMR0IF = 0; // reset overflow bit (for timer0).

				if(spi_state==0){  //If state == 0 we read first thermocouple
					LATCbits.LATC1=0;
					
					SPI_response[0] = ReadSPI();
					SPI_response[1] = ReadSPI();
					SPI_response[2] = ReadSPI();
					SPI_response[3] = ReadSPI();
	
					LATCbits.LATC1=1;
					spi_state = 1;
					
					for(i=0;i<4;i++){
						SPI_lastmessage[i] = SPI_response[i];
					}
					
					if(LED[0] < 2){
						if(((SPI_response[3]&0b00000111) > 0) || ((SPI_response[1]&0b00000001) > 0) ){ //LED brights if TC has an error
							LATCbits.LATC2=1;
							LED[0] = 1;
						} else {
							LATCbits.LATC2=0;
							LED[0] = 0;
						}
					} else if(LED[0] == 2) {
						LATCbits.LATC2=1;
					} else LATCbits.LATC2=0;
					
				} else { //If state == 1 we read second thermocouple
	
					LATCbits.LATC0=0;
					SPI_response[4] = ReadSPI();
					SPI_response[5] = ReadSPI();
					SPI_response[6] = ReadSPI();
					SPI_response[7] = ReadSPI();
	
					LATCbits.LATC0=1;
					spi_state = 0;
					for(i=4;i<8;i++){
						SPI_lastmessage[i] = SPI_response[i];
					}
					if(LED[1] < 2){
						if(((SPI_response[7]&0b00000111) > 0) || ((SPI_response[5]&0b00000001) > 0) ){   //LED brights if TC has an error
							LATCbits.LATC3=1;
							LED[1] = 1;
						} else {
							LATCbits.LATC3=0;
							LED[1] = 0;
						}
					} else if(LED[1] == 2) {
						LATCbits.LATC3=1;
					} else LATCbits.LATC3=0;
				}

			}	
	
	}	//This return will be a "retfie fast", since this is in a #pragma interrupt section 
	#pragma interruptlow YourLowPriorityISRCode
	void YourLowPriorityISRCode()
	{
		//Check which interrupt flag caused the interrupt.
		//Service the interrupt
		//Clear the interrupt flag
		//Etc.
	
	}	//This return will be a "retfie", since this is in a #pragma interruptlow section 

/** DECLARATIONS ***************************************************/
#if defined(__18CXX)
    #pragma code
#endif

/******************************************************************************
 * Function:        void main(void)
 *
 * Overview:        Main program entry point.
 *
 * Note:            None
 *****************************************************************************/
void Interrupts_enable(void) 
{    
  
	T0CONbits.T08BIT = 0; //60ms at 48Mhz. //TconvMAX31855 = 100ms
	T0CONbits.T0CS = 0;
	T0CONbits.PSA = 0;
	T0CONbits.T0PS2 = 0;
	T0CONbits.T0PS1 = 1;
	T0CONbits.T0PS0 = 1;
	TMR0H = 0x50;
	TMR0L = 0x38;
	T0CONbits.TMR0ON = 1;

	RCONbits.IPEN       = 1;    //Enable Interrupt Priorities
    INTCONbits.GIEL     = 1;    //Enable Low Priority Interrupt
    INTCONbits.GIEH     = 1;    //Enable high priority interrupts        
    INTCONbits.TMR0IE   = 1;    //Enable Timer0 Interrupt
	INTCONbits.T0IE     = 1;   
    INTCON2bits.TMR0IP  = 1;    //TMR0 set to low Priority Interrupt
    INTCONbits.TMR0IF = 0;  // T0 int flag bit cleared before starting
    T0CONbits.TMR0ON = 1;   // timer0 START
	INTCONbits.GIE = 1; 		   //Enable all unmasked interrupts   
} 

#if defined(__18CXX)
void main(void)
#else
int main(void)
#endif
{   
	InitializeSystem();
	Interrupts_enable();
	TRISC=0X00;
	LATCbits.LATC0=1;
	LATCbits.LATC1=1;
	TRISB=0b00111111;
	ANSELHbits.ANS10 = 0;
	OpenSPI(SPI_FOSC_16,MODE_00,SMPEND);

    while(1)
    {
        #if defined(USB_INTERRUPT)
            if(USB_BUS_SENSE && (USBGetDeviceState() == DETACHED_STATE))
            {
                USBDeviceAttach();
            }
        #endif

        #if defined(USB_POLLING)
		// Check bus status and service USB interrupts.
        USBDeviceTasks(); // Interrupt or polling method.  If using polling, must call
        				  // this function periodically.  This function will take care
        				  // of processing and responding to SETUP transactions 
        				  // (such as during the enumeration process when you first
        				  // plug in).  USB hosts require that USB devices should accept
        				  // and process SETUP packets in a timely fashion.  Therefore,
        				  // when using polling, this function should be called 
        				  // regularly (such as once every 1.8ms or faster** [see 
        				  // inline code comments in usb_device.c for explanation when
        				  // "or faster" applies])  In most cases, the USBDeviceTasks() 
        				  // function does not take very long to execute (ex: <100 
        				  // instruction cycles) before it returns.
        #endif
    				  

		// Application-specific tasks.
		// Application related code may be added here, or in the ProcessIO() function.
        ProcessIO();        
    }//end while
}//end main

/********************************************************************
 * Function:        float bin2tempint(unsigned char binary, unsigned char binary2)
 *					float bin2tempext(unsigned char binary, unsigned char binary2)
 *
 * Overview:        Converts the messages from the MAX31855 to float.
 *                  
 *                  
 *
 *                  
 *                                    
 *
 * Note:            None
 *******************************************************************/

void bin2temp(unsigned char binary,unsigned char binary2, unsigned char mode){
	char neg = 0; //neg == 0 if number is positive
    convtemperature = 0;
	convtemperature_decimal = 0;

	if((binary2&0b10000000) == 0b10000000){
		neg = 1;
		if(mode==2) binary = binary^0b11111100;
		if(mode==1) binary = binary^0b11110000;
		binary2 = binary2^0b11111111;
	}

	if(mode == 1) {
		if(neg==1 && binary < 240) binary = binary+0b00010000;
		else if(neg==1) {
			binary = 0;
			binary2 += 1;
		}
	    if((binary&0b00000001) == 0b00000001){
	    //thermocouple is open circuit
	        convtemperature = -300;
	        return;
		}
		if((binary&0b00000010) == 0b00000010){
	    //thermocouple is short-circuit to GND
	        convtemperature = -301;
			return;
		}
		if((binary&0b00000100) == 0b00000100){
	        //thermocouple is short-circuit to Vcc
	        convtemperature = -302;
			return;
		}
		if((binary&0b00010000) == 0b00010000)convtemperature_decimal += 6; //0.0625
		if((binary&0b00100000) == 0b00100000)convtemperature_decimal += 12; //0.125
		if((binary&0b01000000) == 0b01000000)convtemperature_decimal += 25;//0.25
	    if((binary&0b10000000) == 0b10000000)convtemperature_decimal += 50; //0.5
		if((binary2&0b00010000) == 0b00010000)convtemperature = convtemperature + 16;
	    if((binary2&0b00100000) == 0b00100000)convtemperature = convtemperature + 32;
	    if((binary2&0b01000000) == 0b01000000)convtemperature = convtemperature + 64;
	} else {
		mode = 16;
		if(neg==1 && binary < 252){
			binary = binary+0b00000100;
		} else if(neg==1) {
			binary = 0;
			binary2 += 1;
		}
	    if((binary&0b00000001) == 1){
	        convtemperature = -303;
			return;
		}
	    if((binary&0b00000100) == 0b100) convtemperature_decimal += 25; //0.25 
	    if((binary&0b00001000) == 0b1000)convtemperature_decimal += 50; // 0.5
		if((binary&0b00010000) == 0b00010000)convtemperature += 1;
		if((binary&0b00100000) == 0b00100000)convtemperature += 2;
	    if((binary&0b01000000) == 0b01000000)convtemperature += 4;
	    if((binary&0b10000000) == 0b10000000)convtemperature += 8;
	    if((binary2&0b00010000) == 0b00010000)convtemperature = convtemperature + 256;
	    if((binary2&0b00100000) == 0b00100000)convtemperature = convtemperature + 512;
	    if((binary2&0b01000000) == 0b01000000)convtemperature = convtemperature + 1024;

	}   //MODE SHOULD BE 1 OR 2
		
		if((binary2&0b00000001) == 0b00000001)convtemperature += (1*mode);
	    if((binary2&0b00000010) == 0b00000010)convtemperature += (2*mode);
	    if((binary2&0b00000100) == 0b00000100)convtemperature += (4*mode);
	    if((binary2&0b00001000) == 0b00001000)convtemperature += (8*mode);
		if(neg==1){
			convtemperature *= -1;
			convtemperature_decimal *= -1;
		}
}
/********************************************************************
 * Function:        ftoa(unsigned char *buf, float f)
 *
 * Overview:        Float to String
 *                  
 *                  
 *
 *                  
 *                                    
 *
 * Note:            None
 *******************************************************************/

char ftoa(unsigned char *buf) {
        unsigned char *s,length=0,length_dec=0,dec[2];

		rem = 0;
        i = convtemperature;
 
        s = buf;
        if (i == 0 && convtemperature_decimal == 0 ){            //print 0.0 with null termination here
                *s++ = '0';
                *s++ = '.';
                *s++ = '0';
				*s++ = '0';
                *s=0;                   //null terminate the string
        } else {       
                if (i < 0 || convtemperature_decimal < 0) {
                        *buf++ = '-';
                        s = buf;
                        if (i < 0) i = -i;
                }
                //while-loop to "decode" the long integer to ASCII by append '0', string in reverse manner
                //If it is an integer of 124 -> string = {'4', '2', '1'}	
				if(i == 0){
                	++length;
                	*s++ = '0';
				}
                while (i) {
                        ++length;
                        rem = i % 10;
                        *s++ = rem + '0';
                        i /= 10;
                }
                //reverse the string in this for-loop, string became {'1', '2', '4'} after this for-loop
                for(rem=0; ((unsigned char)rem)<length/2; rem++) {
                        *(buf+length) = *(buf+((unsigned char)rem));
                        *(buf+((unsigned char)rem)) = *(buf+(length-((unsigned char)rem)-1));
                        *(buf+(length-((unsigned char)rem)-1)) = *(buf+length);
                }
				
				i = convtemperature_decimal;
				if (i < 0) i = -i;
        		if (i == 0 && length<4){            //print 0.0 with null termination here
                	*(buf+length+2) = '0'; //second decimal
					*(buf+length+1) = '0'; //third decimal
	                *(buf+length)='.';                   //null terminate the string
					*(s+3)=0; 
					length += 2;
        		} else if(length<4){
					rem = 0;
					dec[1] = '0';
	                while (i) {
	                        rem = i % 10;
	                        dec[length_dec] = rem + '0';
	                        i /= 10;
							++length_dec;
	                }
                	*(buf+length+2) = dec[0]; //second decimal
					*(buf+length+1) = dec[1]; //third decimal
	                *(buf+length)='.';                   //null terminate the string
					*(s+3)=0; 
					length += 2;
				} else{
					*(s)=0;
					length--;
				}
                      //null terminate
                /* Take care of the special case of 0.x if length ==1*/
				/*
                if(length==1) {
                        *(buf+3) = *buf;
                        *buf = '0';
                        *(buf+1) = '.';
						*(buf+2) = '0';
                        *(s+3)=0;                       //null terminate
				} else {
                        *(buf+length) = *(buf+length-1);
						*(buf+length-1) = *(buf+length-2);
                        *(buf+length-2)='.';
                        *(s+2)=0;                       //null terminate
                }*/
        }
		return (length+1);
 }

/********************************************************************
 * Function:        static void InitializeSystem(void)
 *
 * Overview:        InitializeSystem is a centralize initialization
 *                  routine. All required USB initialization routines
 *                  are called from here.
 *
 *                  User application initialization routine should
 *                  also be called from here.                  
 *
 * Note:            None
 *******************************************************************/
static void InitializeSystem(void)
{
/*
    #if (defined(__18CXX) & !defined(PIC18F87J50_PIM) & !defined(PIC18F97J94_FAMILY))
        ADCON1 |= 0x0F;                 // Default all pins to digital

    #if defined(PIC18F45K50_FAMILY)
        //Configure oscillator settings for clock settings compatible with USB 
        //operation.  Note: Proper settings depends on USB speed (full or low).
        #if(USB_SPEED_OPTION == USB_FULL_SPEED)
            OSCTUNE = 0x80; //3X PLL ratio mode selected
            OSCCON = 0x70;  //Switch to 16MHz HFINTOSC
            OSCCON2 = 0x10; //Enable PLL, SOSC, PRI OSC drivers turned off
            while(OSCCON2bits.PLLRDY != 1);   //Wait for PLL lock
            *((unsigned char*)0xFB5) = 0x90;  //Enable active clock tuning for USB operation
        #endif
        //Configure all I/O pins for digital mode (except RA0/AN0 which has POT on demo board)
        ANSELA = 0x01;
        ANSELB = 0x00;
        ANSELC = 0x00;
        ANSELD = 0x00;
        ANSELE = 0x00;
    #endif
*/
//	The USB specifications require that USB peripheral devices must never source
//	current onto the Vbus pin.  Additionally, USB peripherals should not source
//	current on D+ or D- when the host/hub is not actively powering the Vbus line.
//	When designing a self powered (as opposed to bus powered) USB peripheral
//	device, the firmware should make sure not to turn on the USB module and D+
//	or D- pull up resistor unless Vbus is actively powered.  Therefore, the
//	firmware needs some means to detect when Vbus is being powered by the host.
//	A 5V tolerant I/O pin can be connected to Vbus (through a resistor), and
// 	can be used to detect when Vbus is high (host actively powering), or low
//	(host is shut down or otherwise not supplying power).  The USB firmware
// 	can then periodically poll this I/O pin to know when it is okay to turn on
//	the USB module/D+/D- pull up resistor.  When designing a purely bus powered
//	peripheral device, it is not possible to source current on D+ or D- when the
//	host is not actively providing power on Vbus. Therefore, implementing this
//	bus sense feature is optional.  This firmware can be made to use this bus
//	sense feature by making sure "USE_USB_BUS_SENSE_IO" has been defined in the
//	HardwareProfile.h file.    

    #if defined(USE_USB_BUS_SENSE_IO)
    tris_usb_bus_sense = INPUT_PIN; // See HardwareProfile.h
    #endif
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

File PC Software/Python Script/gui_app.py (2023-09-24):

### Thermo Couple Logger Device
## MakingDevices - 2022/23
#

import sys, time, datetime, csv
from turtle import delay
from PyQt5 import uic, QtCore,QtWidgets
from PyQt5.QtCore import QThread
import matplotlib.pyplot as plt
import matplotlib.dates as dates
from PyQt5.QtWidgets import * 
import serial.tools.list_ports
import pyvisa

COMS = []

import pyvisa, time

rm = pyvisa.ResourceManager()

QtWidgets.QApplication.setAttribute(QtCore.Qt.AA_EnableHighDpiScaling, True) #enable highdpi scaling
QtWidgets.QApplication.setAttribute(QtCore.Qt.AA_UseHighDpiPixmaps, True) #use highdpi icons

# -------------------------
#   TASK CONTROL   --   GLOBAL VARIABLES
# -------------------------
event = '_IDLE_'
state = 'OK'
Loop_number = 0
tc1_internal = 0
tc1_external = 0
tc2_internal = 0
tc2_external = 0
tc1_internal_buffer = 0
tc1_external_buffer = 0
tc2_internal_buffer = 0
tc2_external_buffer = 0
count_packages = 0
comport = 0
x_axis = 100
interrupt_data = 0
tic = 0
toc = 0
tic_sample = 0
toc_sample = 0
TC_LOGGER = None
connection_avail = 0
remove_line = [1,1,1,1]
comm_time = 0.25
sampling_rate = 1
sampling_number = 0
csv_mark = 0
sampling_choice = 0
last_sample = 0
xdata_1 = 0
origin_xdata_1 = 0
graph_choice = 6 
com_description = 0
board_info_bool = 0
board_HW = 0
board_SW = 0

## ---------------------------
##  GRAPH CLASS & RELATED DEFINITIONS
## ---------------------------

class BlitManager:
    def __init__(self, canvas, animated_artists=()):
        """
        Parameters
        ----------
        canvas : FigureCanvasAgg
            The canvas to work with, this only works for sub-classes of the Agg
            canvas which have the `~FigureCanvasAgg.copy_from_bbox` and
            `~FigureCanvasAgg.restore_region` methods.

        animated_artists : Iterable[Artist]
            List of the artists to manage
        """
        self.canvas = canvas
        self._bg = None
        self._artists = []

        for a in animated_artists:
            self.add_artist(a)
        # grab the background on every draw
        self.cid = canvas.mpl_connect("draw_event", self.on_draw)

    def on_draw(self, event):
        """Callback to register with 'draw_event'."""
        cv = self.canvas
        if event is not None:
            if event.canvas != cv:
                raise RuntimeError
        self._bg = cv.copy_from_bbox(cv.figure.bbox)
        self._draw_animated()

    def add_artist(self, art):
        """
        Add an artist to be managed.

        Parameters
        ----------
        art : Artist

            The artist to be added.  Will be set to 'animated' (just
            to be safe).  *art* must be in the figure associated with
            the canvas this class is managing.

        """
        if art.figure != self.canvas.figure:
            raise RuntimeError
        art.set_animated(True)
        self._artists.append(art)

    def _draw_animated(self):
        """Draw all of the animated artists."""
        fig = self.canvas.figure
        for a in self._artists:
            fig.draw_artist(a)

    def update(self):
        """Update the screen with animated artists."""
        cv = self.canvas
        fig = cv.figure
        # paranoia in case we missed the draw event,
        if self._bg is None:
            self.on_draw(None)
        else:
            # restore the background
            cv.restore_region(self._bg)
            # draw all of the animated artists
            self._draw_animated()
            # update the GUI state
            cv.blit(fig.bbox)
        # let the GUI event loop process anything it has to do
        cv.flush_events()

# ----------------------------------
#   USB Serial Check
# ----------------------------------

def serial_ports():
    """ Lists serial port names, descriptions and HW IDs
    """
    global com_description
    ports_avail = []
    ports = serial.tools.list_ports.comports()
    for port, desc, hwid in sorted(ports):
        if(hwid[12:16] == "04D8" and hwid[17:21] == "00AA"):
            com_description = desc
            ports_avail.append(port)
    return ports_avail

# ----------------------------------
#   INFO CLASS & RELATED DEFINITIONS
# ----------------------------------

class AnotherWindow(QWidget):
    def __init__(self):
        super().__init__()
        global comport, com_description, board_HW, board_SW
        uic.loadUi("gui_app_2.ui", self)
        self.COM_board.setText(str(comport))
        self.vendor_USB.setText("04D8")
        self.product_USB.setText("00AA")
        self.label_14.setText(str(com_description))
        self.HW_board.setText(str(board_HW))
        self.SW_board.setText(str(board_SW))

# ----------------------------------
#   GUI CLASS & RELATED DEFINITIONS
# ----------------------------------
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

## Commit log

2022-12-19 Adding new project
    Update!
    [ThermoCouple.sch, ThermoCouple_1.sch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]
2023-03-20 Firmware 1.02 done. Validation pending...
    [ThermoDeviceLogger-B_Cu.gbr, ThermoDeviceLogger-B_Mask.gbr, ThermoDeviceLogger-B_Paste.gbr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]
2023-03-23 1.2b Production version finished.
    [ThermoCouple.sch, ThermoCouple_1.sch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]
2023-04-15 Kicad files
2023-04-20 Finishing touches
    [ThermoCouple.kicad_sch, ThermoDeviceLogger.kicad_sch]
2023-04-24 Reconnect function for PC software
    [log_24042023_200558.csv]
2023-09-24 New 1.50 FW release. Final version for both SW and HW. I also uploaded some python scripts and compiled versions so it is easier to communicate with the board and any PC.
    [log_24092023_163344.csv]
